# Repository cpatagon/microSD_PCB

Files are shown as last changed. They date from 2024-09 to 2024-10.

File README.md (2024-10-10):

# Diseño de Circuito Impreso para Conexión con microSD

## Trabajo Práctico Final - Diseño de Circuitos Impresos (DCI)

Este repositorio contiene el trabajo práctico final para la asignatura de Diseño de Circuitos Impresos, parte de la carrera de posgrado en FIUBA.

**Autor:** Luis Gómez  
**Título del Trabajo:** Diseño de Circuito Impreso para Conexión con microSD  
**Descripción:** El proyecto consiste en diseñar una PCB para un conector microSD utilizando KiCad. El objetivo es desarrollar un esquema que incorpore el conector microSD con la correcta asignación de pines para alimentación y comunicación. Posteriormente, se optimizará el diseño de la PCB para asegurar un trazado eficiente de las señales. Finalmente, se generarán los archivos Gerber necesarios para la fabricación de la PCB, fomentando habilidades en el diseño y preparación de circuitos impresos para la producción.

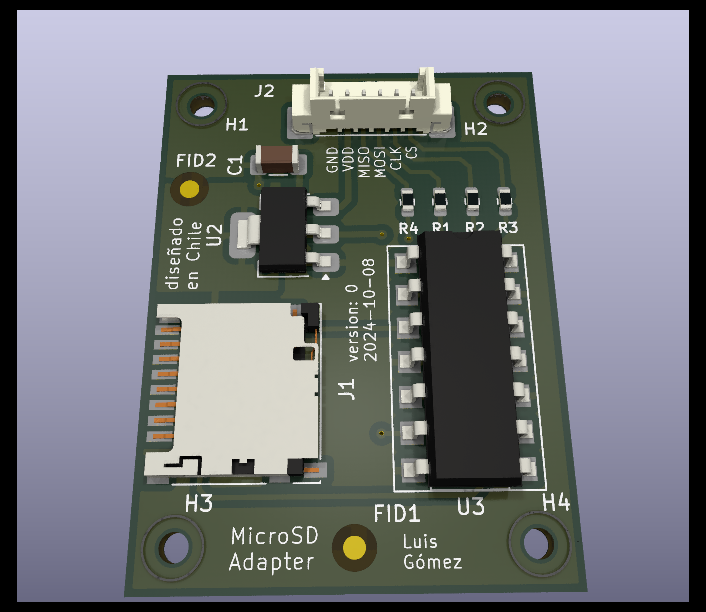
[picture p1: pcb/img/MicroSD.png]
figura 3D de la PCB desarrollada


## Licencia

Este trabajo se encuentra bajo la licencia de hardware abierto. GNU GENERAL PUBLIC LICENSE Version 3, 29 June 2007

## Estructura del Trabajo Práctico Final

* **doc**: Información propia sobre el circuito, incluyendo:
  * [documentación del proyecto](./doc/README.md)
  * [documentación propuesta](./doc/propuesta/README.md)

* **info**: Información recopilada de fuentes externas, como:
  * [información de fuentes externas](./info/README.md)

* **pcb**: Archivos de diseño esquemático y de la PCB.
  * [readme diseño PCB](./pcb/README.md)
  * [PCB Checklist](./pcb/Checklist/README.md)

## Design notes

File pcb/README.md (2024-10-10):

# Proyecto MicroSD: Adaptador PCB

## 1. Información del Proyecto
- **Nombre del diseñador:** Luis Gómez
- **Email:** lgomez@patagones.cl
- **Nombre del proyecto:** PCB microSD
- **Repositorio:** [https://github.com/cese-dci/tpf24a-cpatagon](https://github.com/cese-dci/tpf24a-cpatagon)
- **Revisión realizada por:** Luis Gómez
- **Fecha de la revisión:** 9/10/2024
- **Fecha último commit:** Wed Oct 9 19:16:56 2024 -0300
- **Curso CESE - PCB:** DCI24A

## 2. Resumen Ejecutivo
Este proyecto consiste en el diseño de un adaptador PCB para tarjetas MicroSD, destinado a facilitar la integración de almacenamiento externo en sistemas embebidos. El diseño se enfoca en la compatibilidad con interfaces de 3.3V y 5V, utilizando componentes SMD para minimizar el tamaño y mejorar el rendimiento.

## 3. Especificaciones Técnicas del PCB

| Característica | Valor |
|---|---|
| Cantidad de capas | 2 |
| Terminación superficial | HASL con Plomo |
| Disposición de componentes | Un lado |
| Tecnología de componentes | SMD |
| Serigrafía | 1 cara |
| Grillas utilizadas | 0,5 mm, 0,25 mm, 0,1 mm |
| Anchos de pistas | 0,35 mm y 0,5 mm |
| Vías/agujeros | 0,7 mm / 0,3 mm |
| Clearance (DRC default) | Sin errores |
| Fabricante | [PCB Chile](https://pcb-chile.cl/) |

## 4. Componentes Principales

### 4.1 Integrado 74LVC125A
- **Función:** Buffer cuádruple de tres estados con entradas tolerantes a 5V.
- **Aplicación:** Adaptación de niveles lógicos y aislamiento de señales.
- **Diagrama:**

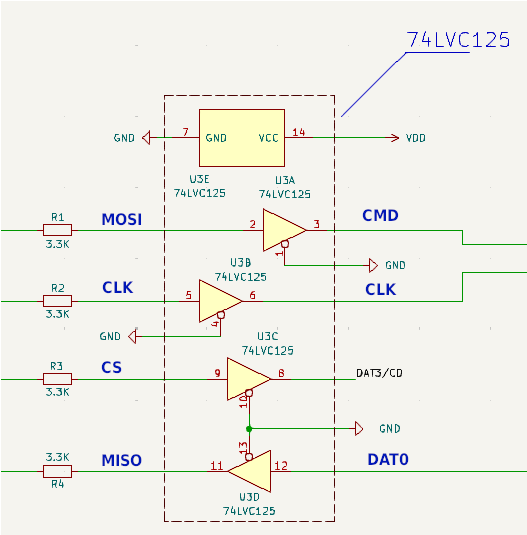
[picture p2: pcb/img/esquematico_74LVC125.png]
Diagrama lógico 74LVC125A
    
  *Figura 1: Diagrama lógico 74LVC125A*

- **Huella:**

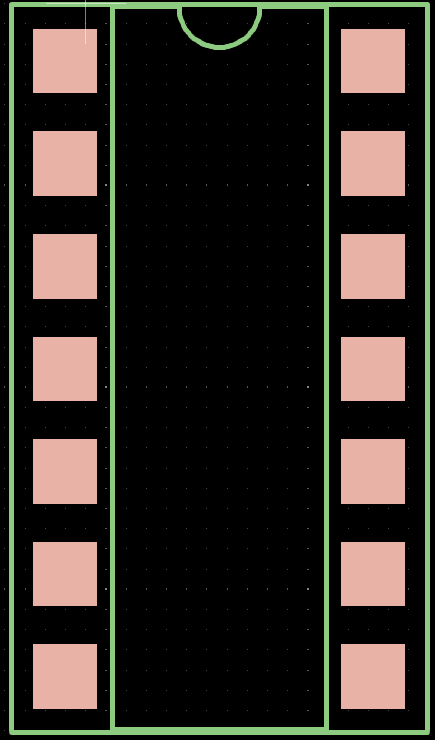
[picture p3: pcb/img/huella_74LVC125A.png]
Huella 74LVC125A
    
  *Figura 2: Huella del integrado 74LVC125A*

### 4.2 Regulador AMS1117
- **Función:** Regulador de voltaje lineal de baja caída.
- **Especificaciones:** Hasta 1A de corriente de salida, comúnmente usado para regular 5V a 3.3V.
- **Diagrama:**

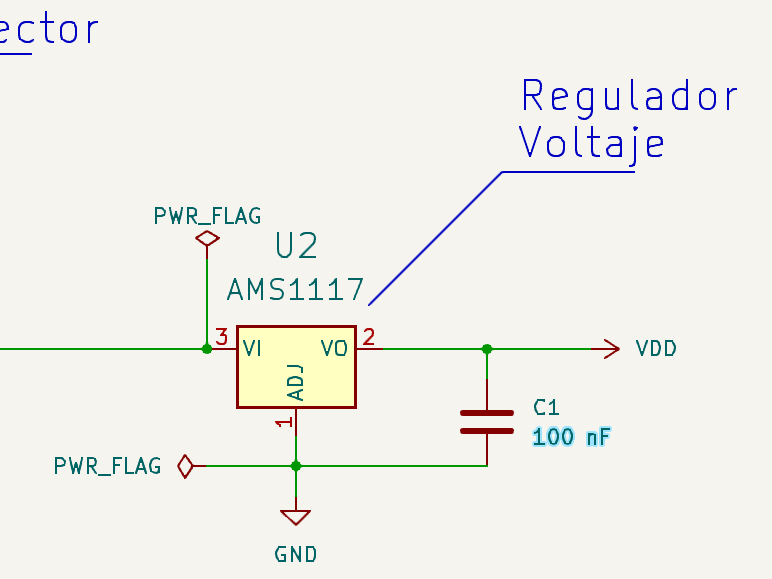
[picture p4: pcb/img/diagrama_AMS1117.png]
Diagrama AMS1117
    
  *Figura 3: Diagrama lógico del regulador AMS1117*

- **Huella:**

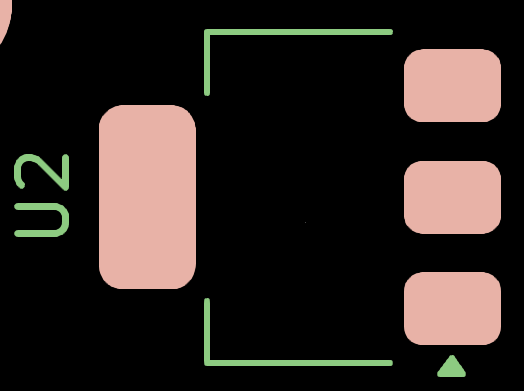
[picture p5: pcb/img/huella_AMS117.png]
Huella AMS1117
    
  *Figura 4: Huella del regulador AMS1117*

### 4.3 Conector MicroSD
- **Función:** Interfaz física para la tarjeta MicroSD.
- **Diagrama:**

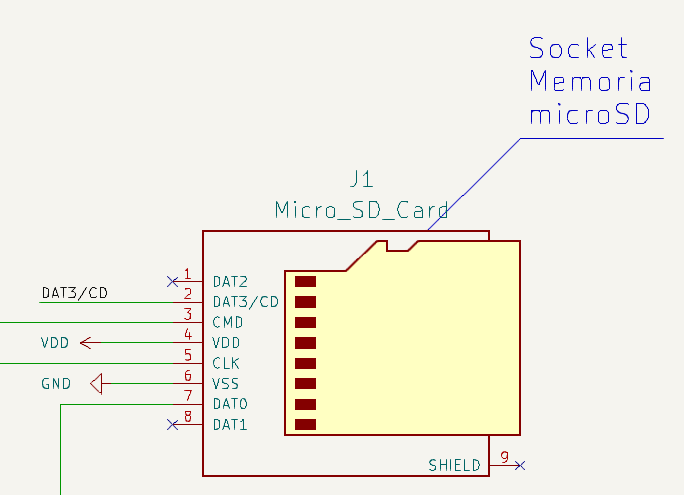
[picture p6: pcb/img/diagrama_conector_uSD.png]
Diagrama conector MicroSD
    
  *Figura 5: Diagrama del conector MicroSD*

- **Huella:**

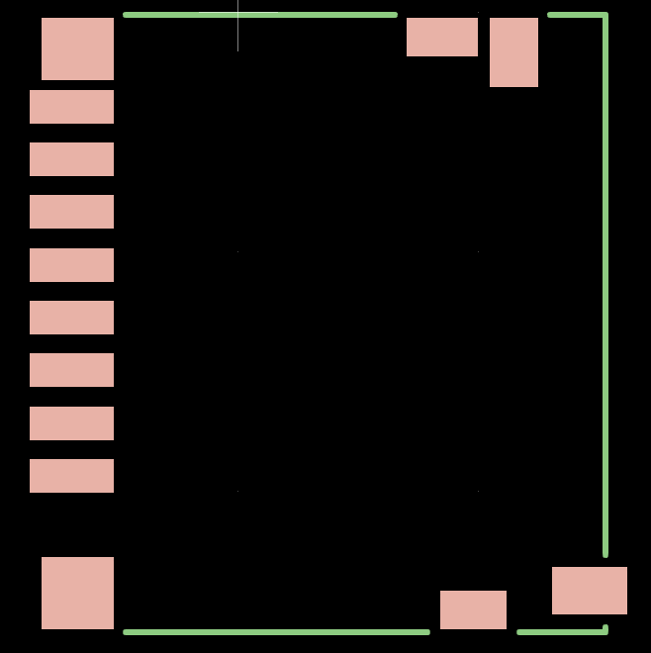
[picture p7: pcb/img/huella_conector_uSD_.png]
Huella conector MicroSD
    
  *Figura 6: Huella del conector MicroSD*

## 5. Diseño del PCB

### 5.1 Esquemático General
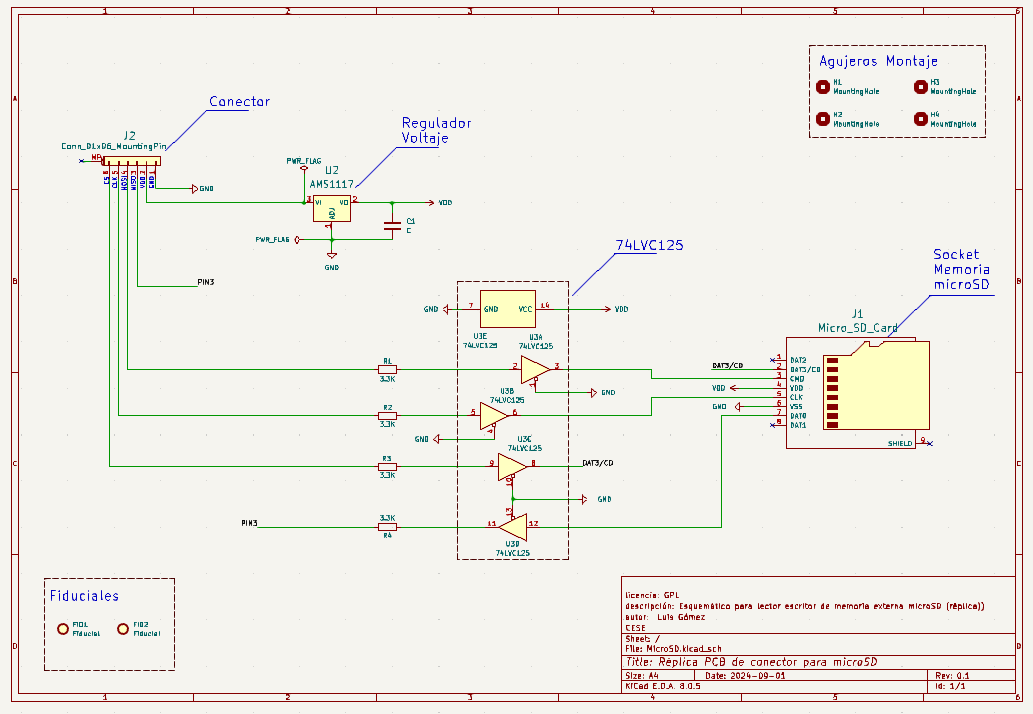
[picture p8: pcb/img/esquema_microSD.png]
Esquemático general
  
*Figura 7: Esquemático general de la PCB MicroSD*

Para más detalles, consulte el [PDF del esquemático completo](PDF/MicroSD.pdf).

### 5.2 Vista General del PCB
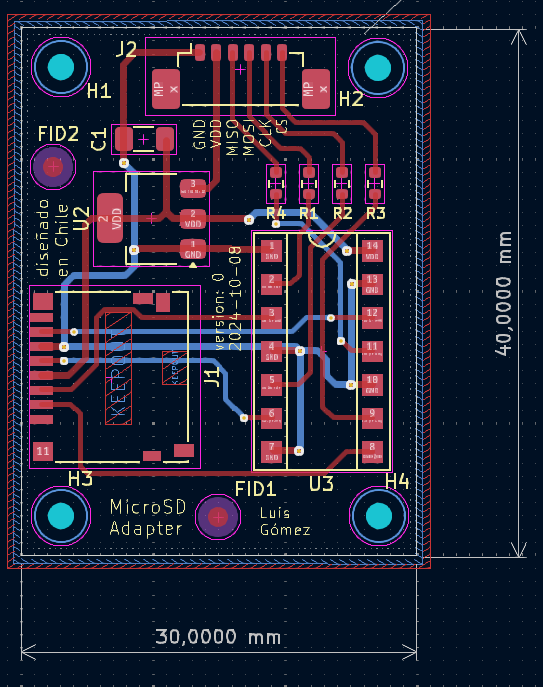
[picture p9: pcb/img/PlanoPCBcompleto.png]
Vista general PCB
  
*Figura 8: Vista general de la PCB para MicroSD*

### 5.3 Huellas de Componentes en PCB
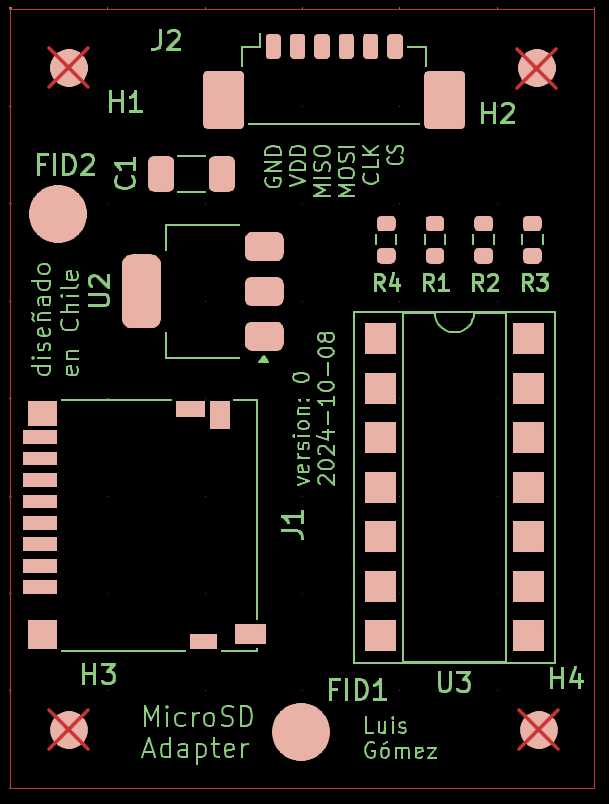
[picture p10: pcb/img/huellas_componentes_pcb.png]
Huellas de componentes
  
*Figura 9: Gerber general con las principales huellas de la PCB*

## 6. Modelos 3D

### 6.1 Vista General 3D
Modelo 3D general  
*Figura 10: Vista general del modelo 3D de la PCB MicroSD*

### 6.2 Vista Frontal 3D
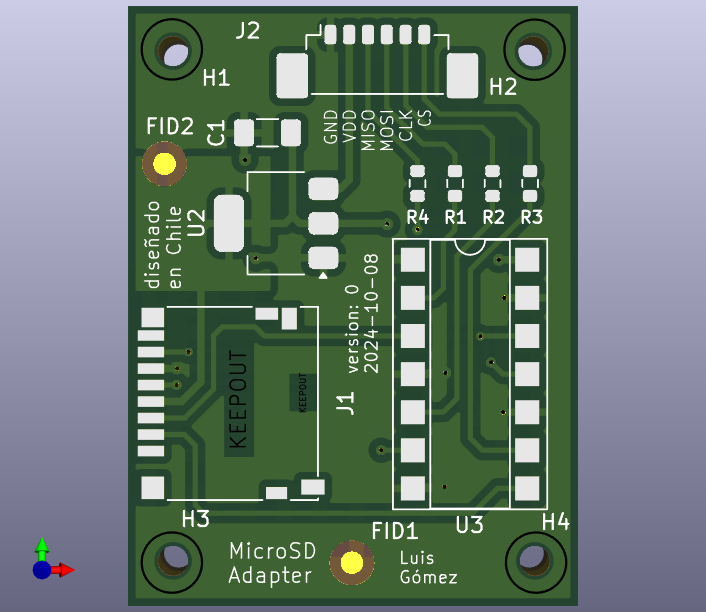
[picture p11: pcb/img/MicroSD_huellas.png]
Vista frontal 3D
  
*Figura 11: Vista frontal del modelo 3D con huellas de componentes*

### 6.3 Vista Trasera 3D
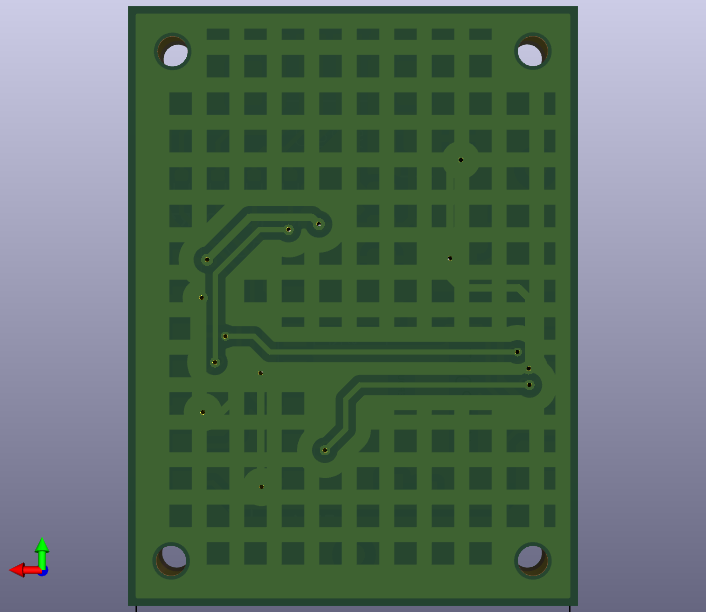
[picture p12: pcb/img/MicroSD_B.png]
Vista trasera 3D
  
*Figura 12: Vista trasera del modelo 3D*

## 7. Archivos del Proyecto

### 7.1 Archivos Gerber
Los archivos Gerber necesarios para la fabricación se encuentran en la [carpeta Gerber](Gerber).

### 7.2 Archivos de PCB
Los archivos de diseño de PCB se encuentran en la [carpeta PCB](MicroSD).

- [Archivo PCB Kicad](MicroSD/MicroSD.kicad_pcb)
- [Archivo Esquematico (sch) Kicad](MicroSD/MicroSD.kicad_sch)

#### Estructura del directorio

```
└── MicroSD
    ├── MicroSD.kicad_pcb (PCB)
    ├── MicroSD.kicad_prl
    ├── MicroSD.kicad_pro
    ├── MicroSD.kicad_sch (Esquematico)
    └── sym-lib-table
```

### 7.3 Bibliotecas de Símbolos y Huellas
Las bibliotecas personalizadas utilizadas en este proyecto se encuentran en la [carpeta Libreria](Libreria).

## 8. Consideraciones de Diseño
- Se utilizó un enfoque de ruteo de dos capas para optimizar el espacio y reducir la interferencia electromagnética.
- Se implementaron planos de tierra en ambas capas para mejorar el manejo de EMI.
- Se calculo el ancho mínimo de cada pista de acuerdo a la norma IPC 2221. Se calculo fue hecho con una corriente máxima de 1A, aumento de la temperatura de 10°C y longitud máxima de pista de 100 mm. El ancho de pista resultante fue de 0,3 mm y un grosor de 1 oz de Cu. 

## 9. Próximos Pasos
- Fabricación de prototipos para pruebas y validación.
- Realización de pruebas de funcionamiento a diferentes voltajes (3.3V y 5V).
- Análisis térmico bajo carga máxima.
- Consideración de mejoras para futuras versiones, como la integración de un controlador USB o soporte para velocidades UHS-I.
- Las pistas de datos se diseñaran con impedancia controlada para mantener la integridad de la señal en altas velocidades.

## 10. Conclusiones
Este diseño de PCB para adaptador MicroSD ofrece una solución compacta y versátil para la integración de almacenamiento externo en sistemas embebidos, con consideraciones especiales para la compatibilidad de voltajes y el rendimiento de alta velocidad.

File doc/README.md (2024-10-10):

# Documentación Detallada: PCB Adaptador MicroSD

## 1. Información del Proyecto
- **Nombre del diseñador:** Luis Gómez
- **Email:** lgomez@patagones.cl
- **Nombre del proyecto:** Adaptador PCB MicroSD de Bajo Costo
- **Repositorio:** [https://github.com/cese-dci/tpf24a-cpatagon](https://github.com/cese-dci/tpf24a-cpatagon)
- **Versión:** 1.0
- **Fecha de última actualización:** 9 de octubre de 2024

## 2. Resumen Ejecutivo
Este proyecto consiste en el diseño de un adaptador PCB para tarjetas MicroSD, enfocado en proporcionar una solución de bajo costo y alta confiabilidad para aplicaciones embebidas. El diseño incorpora adaptación de niveles lógicos para compatibilidad con sistemas de 3.3V y 5V, utilizando componentes SMD para minimizar el tamaño y mejorar el rendimiento.

## 3. Notas de Ingeniería

### 3.1 Arquitectura del Diseño
- **Capas PCB:** Diseño de dos capas para equilibrar complejidad y costo.
- **Tecnología de componentes:** SMD exclusivamente, para reducción de tamaño y mejora de rendimiento en altas frecuencias.
- **Dimensiones del PCB:** 30mm x 20mm (optimizado para portabilidad).

### 3.2 Componentes Clave
1. **Buffer 74LVC125A:**
   - Función: Adaptación de niveles lógicos entre 5V y 3.3V.
   - Justificación: Permite la interoperabilidad con sistemas de diferentes voltajes.

2. **Regulador AMS1117:**
   - Función: Proporciona regulación estable de 3.3V para la tarjeta MicroSD.
   - Características: Baja caída de tensión, capacidad de corriente de 1A.

3. **Conector MicroSD:**
   - Tipo: Push-pull para fácil inserción y extracción.
   - Blindaje: Metálico para reducir EMI.

### 3.3 Consideraciones de Diseño
- **Integridad de la Señal:** Trazado de pistas críticas con impedancia controlada (90 ohms diferencial para líneas de datos SD).
- **EMI/EMC:** Implementación de planos de tierra en ambas capas para reducir interferencias. 
- **Térmica:** Área de cobre ampliada alrededor del regulador AMS1117 para mejorar la disipación térmica.

## 4. Notas de Aplicación

### 4.1 Casos de Uso Previstos
- Sistemas de registro de datos portátiles.
- Actualización de firmware en dispositivos embebidos.
- Almacenamiento expandible para proyectos de IoT.

### 4.2 Guía de Integración
1. **Conexión eléctrica:**
   - Pines de entrada: VCC (5V), GND, MOSI, MISO, SCK, CS.
   - Salida: Interfaz estándar MicroSD.

2. **Configuración de software:**
   - Compatible con bibliotecas estándar de SPI para MicroSD.
   - Ejemplo de código para Arduino y STM32 disponible en el repositorio.

### 4.3 Limitaciones y Precauciones
- Velocidad máxima de operación: 25 MHz (limitado por el buffer 74LVC125A).
- No compatible con el modo UHS-II de tarjetas SD de alta velocidad.

## 5. Estudios Previos y Estado del Arte

### 5.1 Análisis de Mercado
- Revisión de 10 adaptadores MicroSD comerciales (Adafruit, SparkFun, genéricos).
- Tendencia observada: Miniaturización y aumento de la velocidad de transferencia.

### 5.2 Avances Tecnológicos Relevantes
- Nuevos buffers de nivel lógico con menor consumo y mayor velocidad.
- Conectores MicroSD con mejor retención y durabilidad.

### 5.3 Estándares y Normativas
- Cumplimiento con especificaciones SD Association versión 7.0.
- Diseño ajustado a directrices de IPC-2221 para PCB.

## 6. Cálculos y Análisis

### 6.1 Análisis de Potencia
- Consumo estimado:
  - Buffer 74LVC125A: 8 mA (típico)
  - MicroSD (activa): 100 mA (máximo)
  - Regulador AMS1117 (pérdidas): 170 mW (típico con Vin=5V, Iout=100mA)
- Potencia total estimada: < 0.7 W

### 6.2 Análisis Térmico
- Temperatura máxima del regulador AMS1117:
  - Tj = Ta + (Pd * θja) = 25°C + (0.17W * 65°C/W) ≈ 36°C
  - Margen seguro, no requiere disipador adicional.

### 6.3 Cálculos de Ancho de Pista
- Pistas de señal (0.35 mm):
  - Capacidad de corriente: 0.5A a 10°C de elevación de temperatura.
- Pistas de alimentación (0.5 mm):
  - Capacidad de corriente: 1A a 10°C de elevación de temperatura.

### 6.4 Análisis de Integridad de Señal
- Simulación SPICE de líneas diferenciales SD:
  - Rise time: < 1 ns
  - Overshoot: < 10%

## 7. Diagramas y Visualizaciones

### 7.1 Esquemático General
Esquema General
*Figura 1: Esquemático completo del adaptador MicroSD*

### 7.2 Diagrama de Bloques Funcionales
Diagrama de Bloques
*Figura 2: Diagrama de bloques funcionales del adaptador*

### 7.3 Diseño PCB
Huella PCB
*Figura 3: Layout de PCB mostrando huellas de componentes*

### 7.4 Renderizado 3D
Modelo 3D
*Figura 4: Renderizado 3D del PCB ensamblado*

## 8. Presupuesto y Análisis de Costos

### 8.1 Costos de Fabricación (para 100 unidades)
- PCB (PCB Chile): $1.72 USD/unidad (https://pcb-chile.cl/quote)

### 8.2 Costos de Componentes (precios unitarios)
- 74LVC125A: $0.1 USD (https://www.mouser.cl/c/?q=74LVC125A )
- AMS1117: $0.0264 USD  (https://es.aliexpress.com/ )
- Conector MicroSD: $1.47 USD (https://www.mouser.cl/)
- Otros componentes pasivos: $0.50 USD

### 8.3 Costo Total Estimado
- Costo por unidad (incluyendo fabricación y componentes): $7.50 USD
- Precio de venta sugerido: $14.99 USD
- Margen bruto estimado: 50%

## 9. Conclusiones y Trabajo Futuro

### 9.1 Logros del Diseño Actual
- Adaptador MicroSD de bajo costo con adaptación de nivel lógico integrada.
- Tamaño compacto y diseño optimizado.

### 9.2 Áreas de Mejora
- Explorar la posibilidad de integrar RTC
- Investigar opciones para soportar velocidades UHS-I en futuras revisiones.

### 9.3 Próximos Pasos
- Fabricación de prototipo y pruebas de campo.

---

Este documento está sujeto a revisiones y actualizaciones. Última revisión: 09/10/2024.

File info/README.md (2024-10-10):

# Información Complementaria PCB MicroSD

## Hojas de Datos

### 1. Buffer 74LVC125A
- **Fabricante:** Texas Instruments
- **Enlace:** [Hoja de datos 74LVC125A](https://www.ti.com/lit/ds/symlink/sn74lvc125a.pdf)
- **Importancia:** Crucial para la adaptación de niveles lógicos entre 3.3V y 5V.

### 2. Regulador AMS1117
- **Fabricante:** Advanced Monolithic Systems
- **Enlace:** [Hoja de datos AMS1117](http://www.advanced-monolithic.com/pdf/ds1117.pdf)
- **Importancia:** Proporciona la regulación de voltaje necesaria para la tarjeta MicroSD.

### 3. Conector MicroSD
- **Fabricante:** Molex
- **Enlace:** [Hoja de datos Conector MicroSD](https://www.molex.com/pdm_docs/sd/5033981892_sd.pdf)
- **Importancia:** Especificaciones mecánicas y eléctricas para el diseño del footprint.

## Notas de Aplicación

### 1. Diseño de PCB para Tarjetas SD
- **Título:** "PCB Design Guidelines for SD Memory Cards"
- **Fuente:** SD Association
- **Enlace:** [Guía de Diseño SD](https://www.sdcard.org/downloads/pls/pdf/index.php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)
- **Relevancia:** Proporciona pautas específicas para el diseño de PCB compatible con tarjetas SD.

### 2. Consideraciones de EMI en Diseño de PCB
- **Título:** "EMI Reduction Techniques in PCB Design"
- **Fuente:** Analog Devices
- **Enlace:** [Técnicas de Reducción de EMI](https://www.analog.com/media/en/training-seminars/tutorials/MT-095.pdf)
- **Relevancia:** Ayuda a minimizar la interferencia electromagnética en el diseño.

## Información de Productos Comerciales

### 1. Adaptador MicroSD de Adafruit
- **Producto:** Adafruit MicroSD Card Breakout Board
- **Enlace:**:
  - [Adafruit MicroSD Breakout](https://www.adafruit.com/product/254)
  - [Github](https://github.com/adafruit/MicroSD-breakout-board)
- **Uso:** Referencia para comparar características y diseño.

### 2. Módulo MicroSD de SparkFun
- **Producto:** SparkFun MicroSD Transflash Breakout
- **Enlace:** [SparkFun MicroSD Breakout](https://www.sparkfun.com/products/544)
- **Uso:** Inspiración para el diseño y comparación de funcionalidades.

## Recursos de Internet

### 1. Tutorial de Diseño de PCB
- **Título:** "KiCad PCB Design Tutorial"
- **Fuente:** Contextual Electronics
- **Enlace:** [Tutorial KiCad](https://contextualelectronics.com/courses/getting-to-blinky-4-0/)
- **Aplicación:** Guía paso a paso para el diseño de PCB en KiCad.

### 2. Foro de Diseño de PCB
- **Nombre:** EEVblog Electronics Community Forum
- **Enlace:** [Foro EEVblog](https://www.eevblog.com/forum/eda/)
- **Uso:** Discusiones y consejos de la comunidad sobre diseño de PCB.

### 3. Calculadora de Ancho de Pista PCB
- **Herramienta:** PCB Trace Width Calculator
- **Enlace:** [Calculadora de Ancho de Pista](https://www.4pcb.com/trace-width-calculator.html)
- **Aplicación:** Utilizada para determinar el ancho óptimo de las pistas en el PCB.

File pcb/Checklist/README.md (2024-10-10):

# PCB Design Checklist

## Documentación y Organización
| PASA | Ítem | Comentarios | Se pide en la asignatura? |
|---|---|---|---|
| SI | Puso en el directorio /doc/propuesta las imágenes y pdfs del circuito original? Use la información que proporcionó en el formulario. | | SI |
| SI | En el directorio /info colocó las hojas de datos de los chips más importantes del circuito? En particular es de interés la hoja de datos donde figuren los footprints. Como es un ejercicio, no coloque manuales extensos o archivos muy grandes. | | SI |
| SI | Organizó adecuadamente en directorios? Por ejemplo en el directorio del diseño KiCad solo puso los archivos KiCad o mezcló ahí hojas de datos y otros archivos? | | SI |

## Esquemático
| PASA | Ítem | Comentarios | Se pide en la asignatura? |
|---|---|---|---|
| SI | El rótulo tiene el título del diseño? | | SI |
| SI | El título da una idea de que trata el circuito? | | SI |
| SI | Si se trata de la modalidad "Réplica" dice réplica en el título? | | SI |
| SI | El rótulo tiene nombre del autor ? | | SI |
| SI | El rótulo tiene información de la licencia? La licencia es de uso libre como OHL, BSD, GPL o CC BY 4.0 | | SI |
| SI | Las referencias son consecutivas y sin saltos? Por ejemplo R1, R2, R5, R6 (le falta R3). | | SI |
| SI | Están todos los campos de valor de los componentes completados correctamente? | | SI |
| SI | Los campos referencia y valor, se ven claramente y no se superponen con otras cosas? | | SI |
| SI | Los componentes importantes como semiconductores y conectores fuera de lo común, tienen código de catálogo? | | SI |
| ? | Tiene bloques funcionales delimitados claramente? | Los separé espacialmente | SI |
| SI | Hay un texto con el nombre o descripción de cada bloque? | | SI |
| NO | Tiene las notas aclaratorias necesarias? | | SI |
| NO | El ERC da cero errores? Si da errores, no hay forma de sacarlos? | | SI |
| SI | Colocó símbolos para los agujeros y los fiduciales? | | SI |
| SI | Las conexiones más importantes del circuito están dibujadas o hizo "abuso" de etiquetas? | | SI |
| SI | Usó adecuadamente las referencias de tensión para evitar líneas innecesarias? | | SI |
| SI | Uso adecuadamente las referencias de alimentación, o colocó unas pocas y desde ahí salen conexiones a todo el esquemático? | | SI |
| SI | Usó etiquetas locales para conectar dentro de la hoja o usó globales innecesariamente? | | SI |
| SI | Hay algunas señales o nodos que merezcan ser identificadas con una etiqueta (por ejemplo líneas de clock o reset, o líneas principales de comunicación entre bloques). | | SI |
| NO | Si es de múltiples hojas, separó en forma inteligente? Hay más de dos niveles? En caso de ser simple hoja, entra adecuadamente o se nota la falta de espacio en la hoja? | | SI |
| SI | Tiene uniones (junctions) en lugares donde no son necesarias? Hizo un esfuerzo por evitar superponer puntos de conexión con uniones? | | SI |
| SI | Intentó seguir un flujo de izquierda a derecha siempre que se puede? | | SI |
| SI | Intentó dibujar las ramas de arriba hacia abajo según tensiones de alimentación positivas y negativas? | | SI |
| SI | Si es un esquemático jerárquico, las alimentaciones no deben pasarse por etiquetas jerárquicas. | | SI |
| SI | Los circuitos integrados, tiene su disposición de pines ordenados para facilitar el diagrama o están según el pinout físico? | | SI |
| NO | Hay algún circuito integrado o componente que si se dibuja como multiparte tendría un gran impacto positivo en la prolijidad o organización? | | SI |

## Asociación de Huellas
| PASA | Ítem | Comentarios | Se pide en la asignatura? |
|---|---|---|---|
| SI | Todos los símbolos tienen una huella asociada | | SI |
| SI | Tiene por lo menos un agujero de sujeción? Se recomienda uno para los PCBs más pequeños y 2 a 4 para los mayores. | | SI |
| SI | Tiene los fiduciales en caso de ser necesarios? | | SI |
| SI | Verificó las dimensiones de los pads con las hojas de datos? | | SI |
| SI | Verificó el paso y todas las distancias de los componentes con su hoja de datos? | | NO |
| NO | Verificó que las numeraciones sean las correctas en relación al esquemático y a la hoja de datos? | | NO |
| NO | Consideró el requisito de componentes 0805 o más grande? Como regla general, pensó en el posible retrabajo de los componentes o en el armado manual de los primeros prototipos? | | SI |

## PCB: Huellas y Posicionamiento
| PASA | Ítem | Comentarios | Se pide en la asignatura? |
|---|---|---|---|
| SI | Trabajó principalmente en mm? | | SI |
| SI | Anotó las grillas que usa? Cuáles son? | | SI |
| SI | Colocó fiduciales en las esquinas en caso de ser necesarios? | | SI |
| SI | Colocó los agujeros al principio y de manera estratégica? | | SI |
| SI | Los conectores están al borde? | | SI |
| SI | Si se trata de una réplica, miró la disposición original para tener ya una disposición tentativa? (se puede adaptar o mejorar, no tiene que ser una réplica exacta, pero analizar el original lo ayudará a pensar un buen posicionamiento. | | SI |

## Modelos 3D y Portabilidad
| PASA | Ítem | Comentarios | Se pide en la asignatura? |
|---|---|---|---|
| SI | Todos los componentes tienen modelo 3D asociado? Si alguno no tiene, intentó buscarlo? | | SI |
| SI | Colocó todos los modelos 3D dentro del repositorio? La operación se realiza fácilmente con la operación de exportar, una vez que todos los modelos 3D están asociados. | | SI |
| SI | Si tiene la posibilidad, baje el repositorio en otro sistema e intente abrir esquemático, PCB y ver la vista 3D. Esto sirve para detectar archivos faltantes en el repo, o rutas absolutas en el diseño. Idealmente se deben usar siempre rutas relativas que apunten a carpetas y archivos dentro del repo. Le puede pedir a un compañero que lo haga si no posee otra computadora o sistema alternativo. | | SI |

## PCB - Documentación
| PASA | Ítem | Comentarios | Se pide en la asignatura? |
|---|---|---|---|
| SI | El rótulo del PCB tiene información similar al esquemático? | | SI |
| SI | Tiene notas adicionales con la terminación superficial elegida? | | SI |
| SI | Tiene notas adicionales con las grillas utilizadas, o las principales que utilizó? | | SI |
| SI | Si es un multicapa, colocó notas con la información del stackup? | | SI |
| SI | Colocó en las notas, qué fabricante consideró? | Esto se pide para que el docente conozca qué fabricante usó como referencia al momento de analizar los límites del diseño. | SI |
| SI | Dibujó las cotas de las dimensiones principales del PCB? (alto y ancho) | | SI |

## PCB - Borde
| PASA | Ítem | Comentarios | Se pide en la asignatura? |
|---|---|---|---|
| SI | El borde de PCB, lo dibujó usando la capa adecuada para tal fin? | | SI |
| SI | El borde de PCB coincide con la grilla más grande que dice haber utilizado? Por ejemplo 1mm o 0,5 mm. | | SI |
| SI | El tamaño de PCB tiene dimensiones coherentes? | Por ejemplo números redondos (salvo requisito especial). Por ejemplo espacios grandes sin aprovechar. | SI |
| SI | Dibujó el margen de seguridad al borde del PCB? Se sugiere por lo menos 0,5 mm. | | SI |
| SI | Dibujó un margen de seguridad para que los componentes y las estructuras de cobre no estén demasiado cerca del borde? | | SI |

## PCB - Distribución
| PASA | Ítem | Comentarios | Se pide en la asignatura? |
|---|---|---|---|
| SI | La distribución de los componentes en el PCB es pareja? | | SI |
| SI | Los componentes están alineados prolijamente entre sí, siempre que se puede? | | |

## PCB - Rellenos de Cobre
| PASA | Ítem | Comentarios | Se pide en la asignatura? |
|---|---|---|---|
| SI | Analizó el balance de cobre? | | SI |
| SI | Utilizó rellenos de cobre, en especial para las tierras involucradas? | | SI |
| SI | Aplicó alivios térmicos? | | SI |
| SI | Los límites de las zonas de rellenos se superponen entre sí y con el borde o aplicó las sugerencias vistas en clase (siempre que la situación lo permita)? | | SI |

## PCB - Pistas
| PASA | Ítem | Comentarios | Se pide en la asignatura? |
|---|---|---|---|
| SI | Configuró los anchos de pistas que usará en el diseño? | | |
| SI | Las pistas que ingresan a los pads, tienen el ancho necesario para no deformarlos? | | SI |
| SI | Utilizó un ancho de pista acorde al tamaño de los pads, a las corrientes involucradas y que superen los límites de fabricación? | | SI |
| SI | Utilizó pistas a 45 siempre que pudo, en vez de pistas a 90 o a cualquier ángulo? | | SI |
| SI | El ruteo está prolijo? Por ejemplo los trazos no tienen quiebres innecesarios, desprolijidades de trazos, segmentos sueltos, pistas descentradas, etc. | | SI |
| SI | Para las pistas que llevan corrientes importantes, realizó el cálculo del ancho necesario? | | |
| SI | Si tiene impedancia controlada, aplicó el ancho necesario, documentó adecuadamente en PCB y en esquemático? | | |

## PCB - Vías
| PASA | Ítem | Comentarios | Se pide en la asignatura? |
|---|---|---|---|
| SI | Configuró las vías que utilizará en el diseño? | | SI |
| SI | Las vías tienen un tamaño adecuado? Analizó los límites de fabricación y las recomendaciones de IPC? | | SI |

## PCB - Clearance y DRC
| PASA | Ítem | Comentarios | Se pide en la asignatura? |
|---|---|---|---|
| SI | Utilizó el mayor clearance posible que le permite el tipo de diseño? Intentó subirlo? | Muchas veces implica colocar márgenes ajustados (menores) para determinados componentes, pero dejando al resto del PCB con márgenes más amplios. | SI |
| SI | Configuró adecuadamente las reglas de diseño? | | SI |
| SI | Dejó al diseño con cero errores de DRC? | | SI |

## PCB - Serigrafía
| PASA | Ítem | Comentarios | Se pide en la asignatura? |
|---|---|---|---|
| SI | Todas las referencias se leen correctamente y están prolijas? | | SI |
| SI | Ocultó las referencias de fiduciales y agujeros? | Normalmente no son necesarias. | SI |
| SI | Para optimizar costos, muchas veces solo se aplica serigrafía de un solo lado, cuando realmente no es necesario aplicarla de ambos lados, o se puede pasar todo a una cara. Analizó este tema? | | SI |
| SI | Agregó el nombre del circuito? | | SI |
| SI | Agregó una fecha o un número de versión? | | SI |
| SI | Agregó su nombre y/o apellido? | | Opcional |
| SI | Agregó la leyenda "Diseñado en PAIS" o "Industria PAIS"? | | Opcional |

## PCB - Verificación
| PASA | Ítem | Comentarios | Se pide en la asignatura? |
|---|---|---|---|
| NO | Tiene pines para testing? | | NO |
| NO | Tiene leds para las tensiones o señales importantes? | | NO |
| NO | Los tamaños de agujeros para los pines tienen la holgura necesaria para que el pin no entre a presión? | | NO |
| NO | Tiene el verificador de capas? | | Solo si es multicapa |
| NO | Tiene cupón de prueba? Hace falta? | | NO |

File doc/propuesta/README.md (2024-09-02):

## Propuesta

En este directorio se incluye la información presentada al momento de acordar la propuesta del Trabajo Práctico con el docente. A continuación se detallan los elementos clave:

### Fotos e Imágenes

Si el trabajo es una réplica, se presentan las imágenes de las placas de ambos lados:

* **Placa MicroSD (Vista Superior):**  
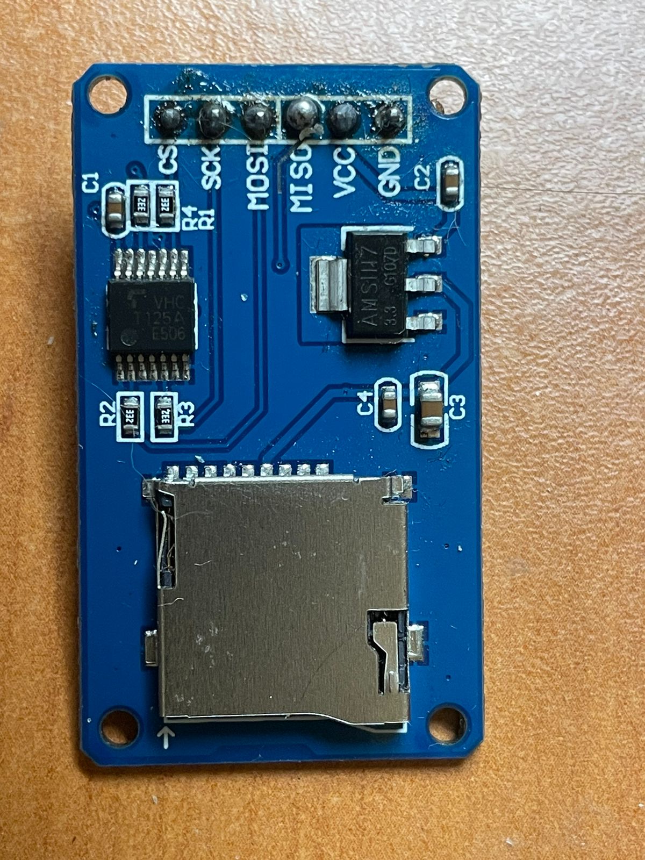
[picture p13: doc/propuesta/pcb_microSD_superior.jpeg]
Vista Superior
  

* **Placa MicroSD (Vista Posterior):**  
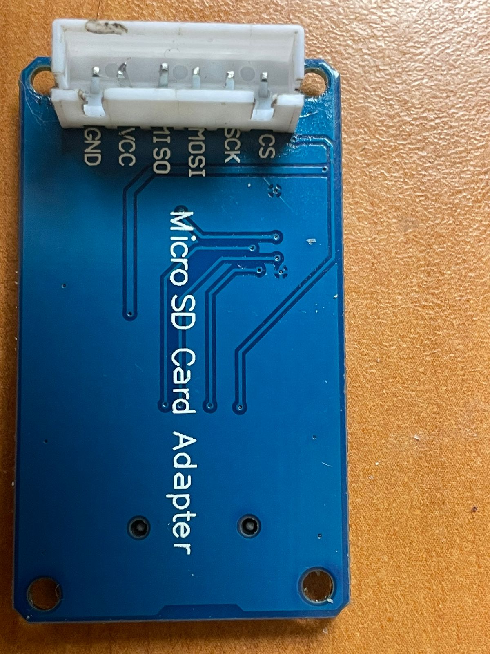
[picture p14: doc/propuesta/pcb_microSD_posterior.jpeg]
Vista Posterior
  

### Circuito Esquemático de Referencia

A continuación, se incluye el esquema de referencia del circuito:

* **Esquemático del Módulo MicroSD:**  
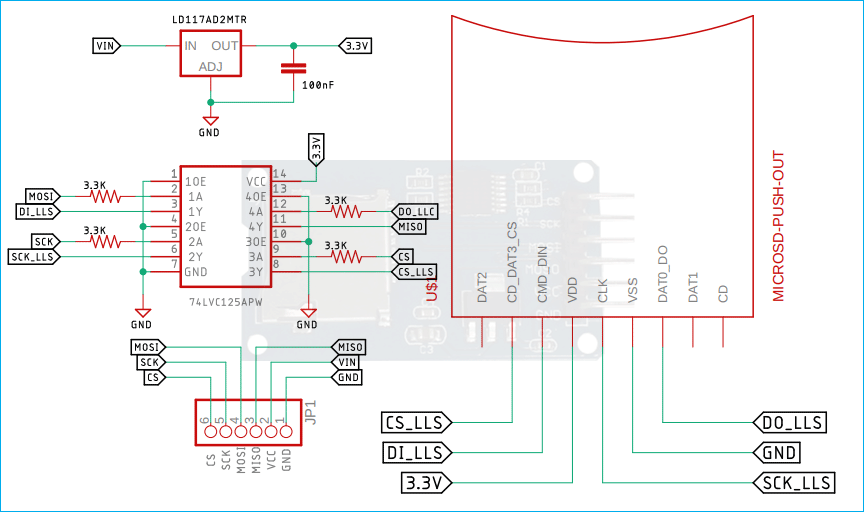
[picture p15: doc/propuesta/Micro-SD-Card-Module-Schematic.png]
Esquemático MicroSD
  

### Documentación Técnica

Se incluyen los siguientes documentos técnicos relacionados con los componentes utilizados en el circuito:

* [AMS1117 - Datasheet](AMS1117.PDF)
* [SN74LVC125A - Datasheet](SN74LVC125A.PDF)

### Información Adicional

Si el trabajo es una tesis, a continuación se resumen las pruebas y prototipos realizados, así como el objetivo del circuito:

* **Resumen del Objetivo del Circuito:**  
  (Incluir aquí un resumen breve del objetivo o función principal del circuito, si es un trabajo de tesis)

* **Pruebas y Prototipos Cableados:**  
  (Incluir imágenes o descripciones de las pruebas realizadas)

### URLs o Información de Origen

Para mayor información y referencias, se incluyen los enlaces y recursos utilizados para definir el TP en el formulario de propuesta:

* **URLs e Información de Origen:**  
  (Incluir aquí las URLs o información relevante que se haya utilizado para la propuesta)

### Notas Adicionales

Cualquier otra nota o comentario que se haya utilizado para definir el TP en el formulario de propuesta se incluirá aquí.

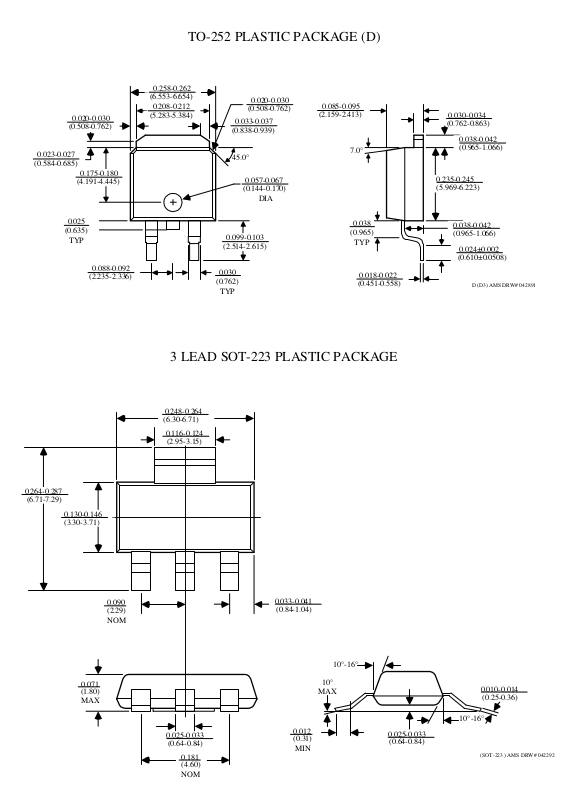
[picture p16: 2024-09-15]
info/img/huella_AMS1117.png

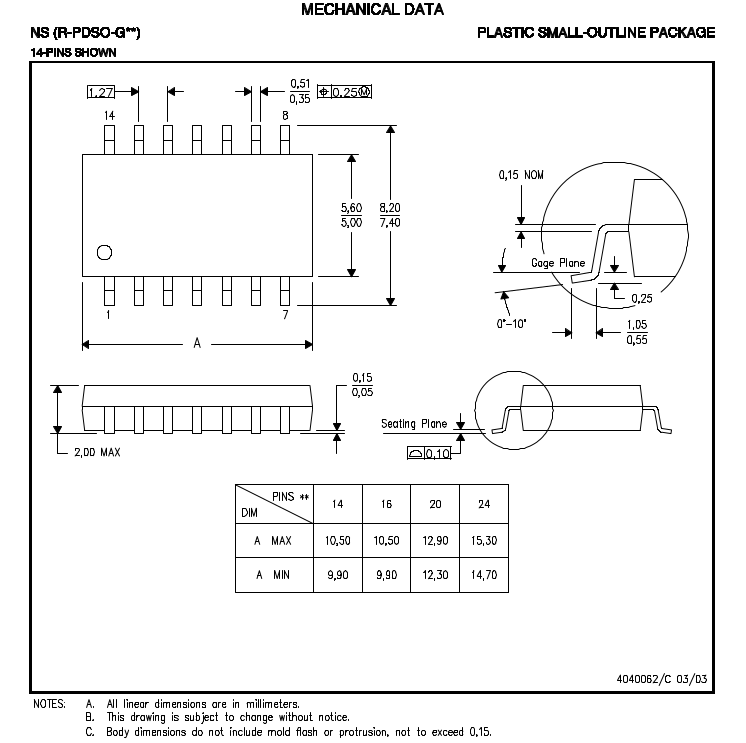
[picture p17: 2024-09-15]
info/img/huella_74LVC125A.png

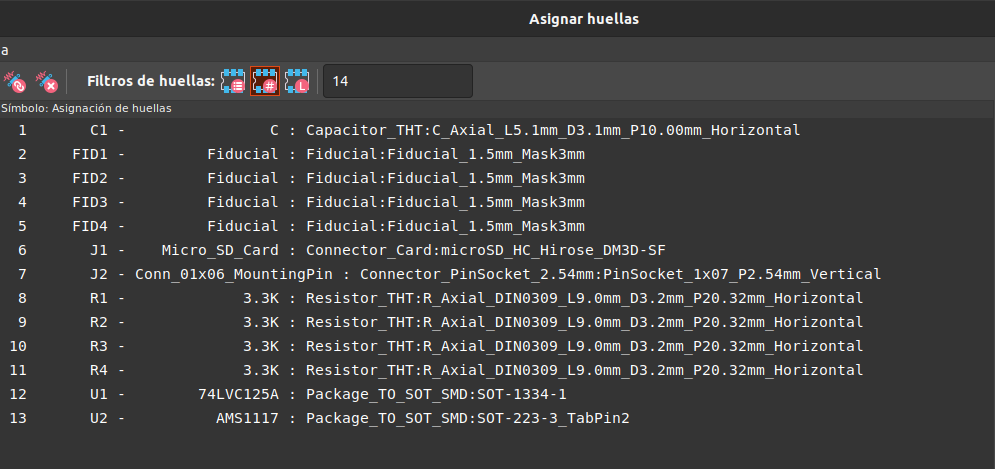
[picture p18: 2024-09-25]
doc/img/huellas.png

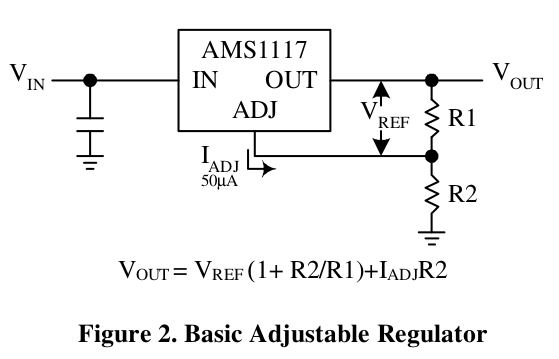
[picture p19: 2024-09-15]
info/img/esquematico_AMS117.png

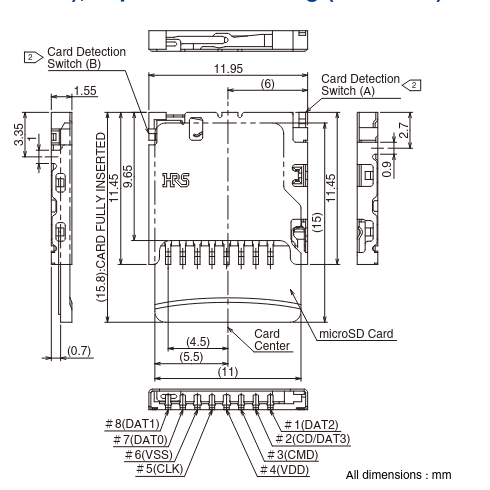
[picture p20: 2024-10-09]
doc/propuesta/Connector_CardmicroSD_HC_Hirose_DM3D-SF.png

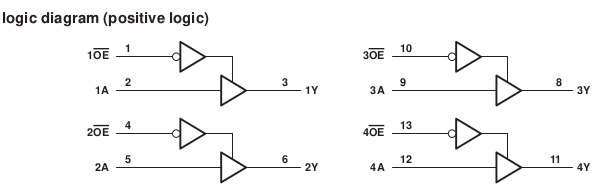
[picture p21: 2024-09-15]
info/img/diagrama_74LVC125A.png

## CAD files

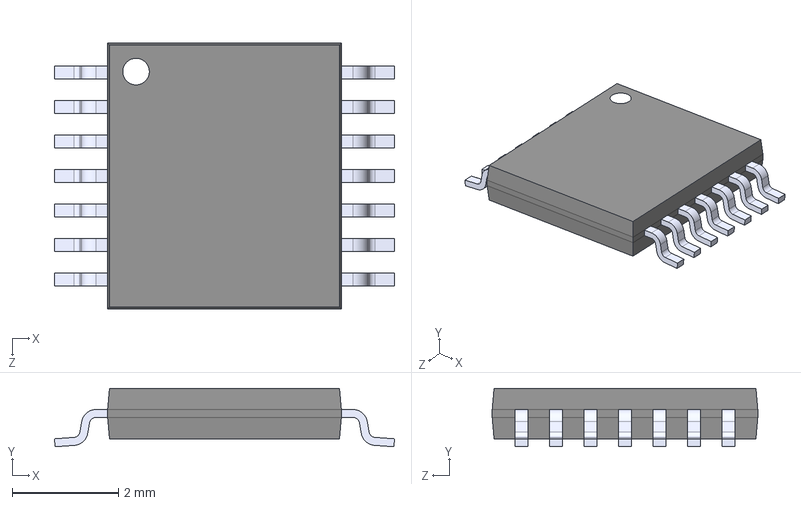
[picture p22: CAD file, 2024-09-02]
pcb/Libreria/74LVC125APW_118.step
6.40 x 1.10 x 5.00 mm

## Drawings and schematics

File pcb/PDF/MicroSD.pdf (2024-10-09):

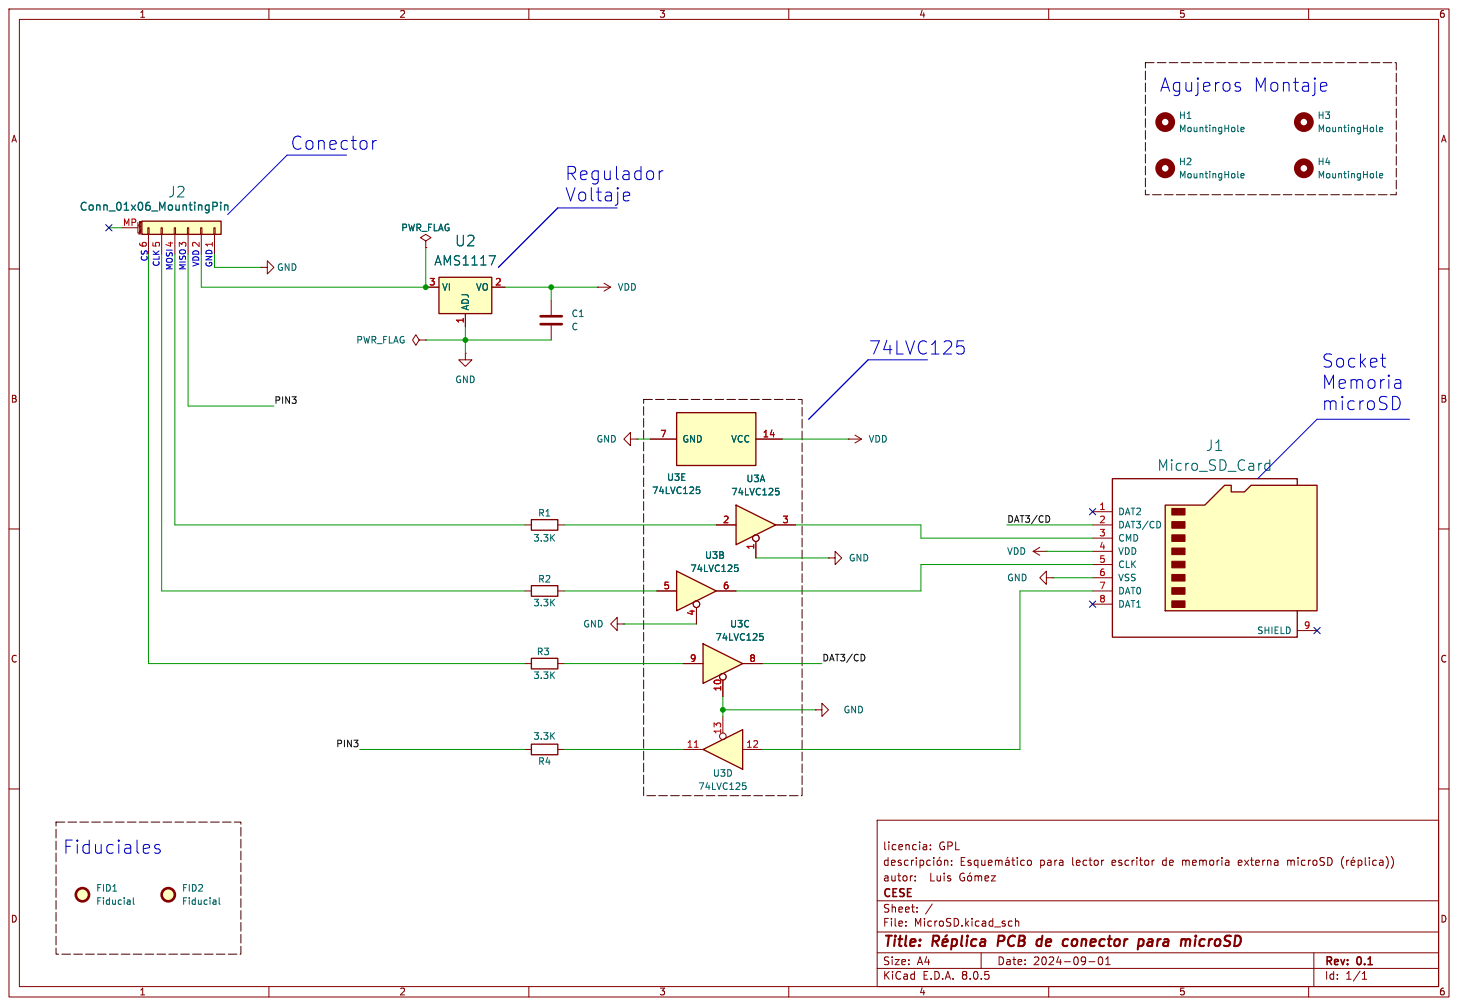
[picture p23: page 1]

File: MicroSD.kicad_sch Sheet: / CESE

Id: 1/1 Title: þÿRéplica PCB de conector para microSD

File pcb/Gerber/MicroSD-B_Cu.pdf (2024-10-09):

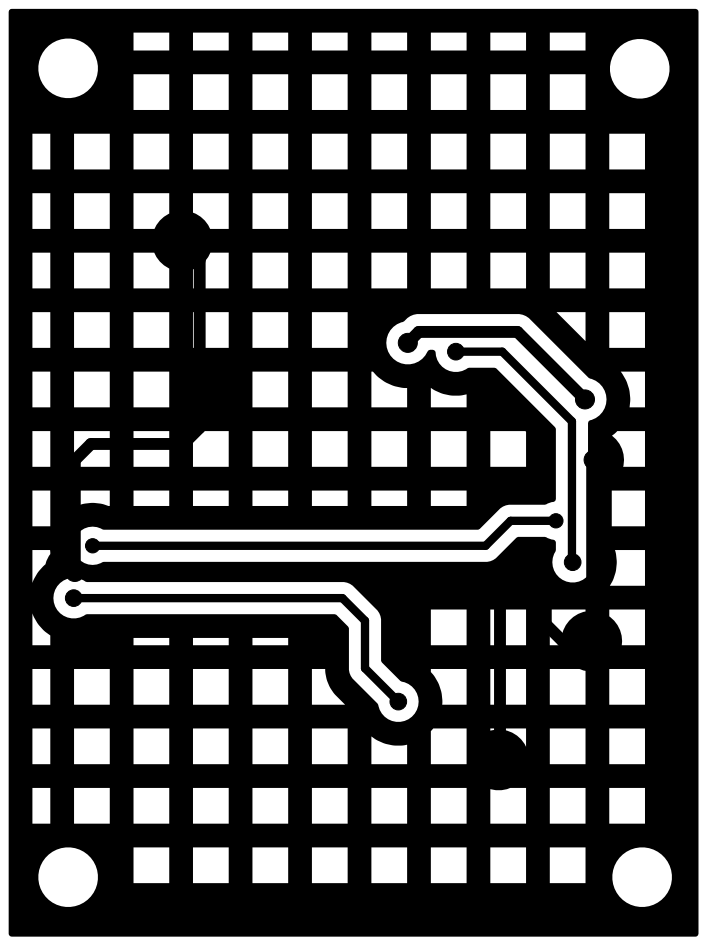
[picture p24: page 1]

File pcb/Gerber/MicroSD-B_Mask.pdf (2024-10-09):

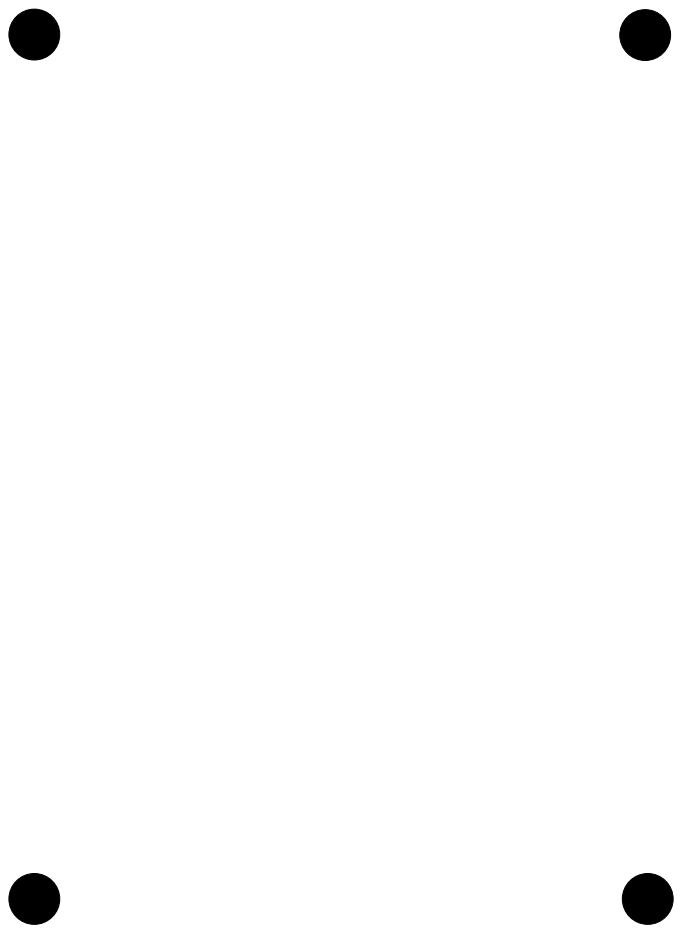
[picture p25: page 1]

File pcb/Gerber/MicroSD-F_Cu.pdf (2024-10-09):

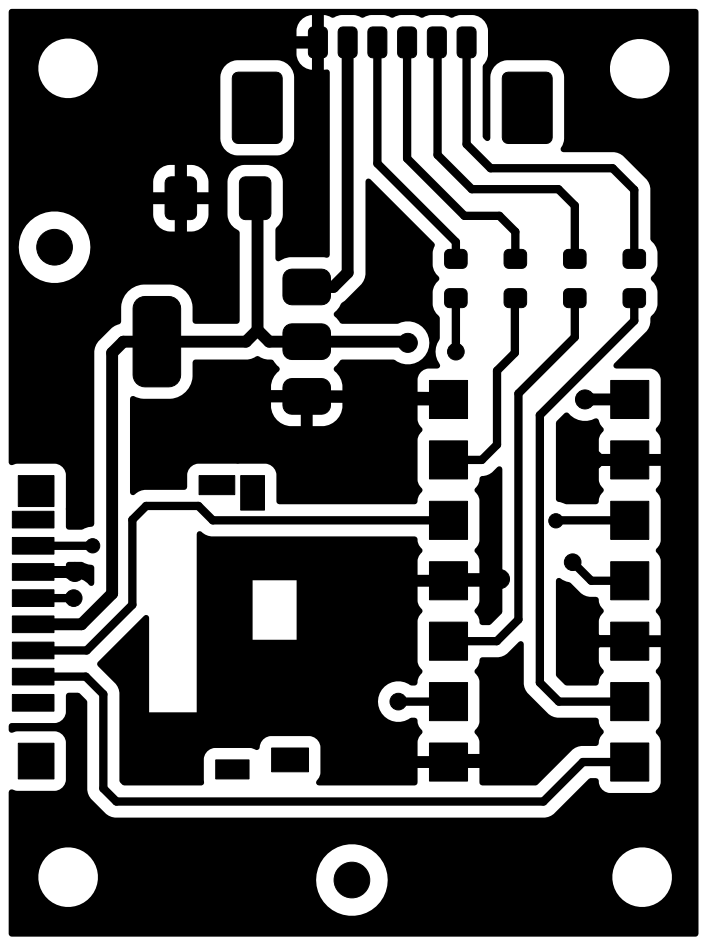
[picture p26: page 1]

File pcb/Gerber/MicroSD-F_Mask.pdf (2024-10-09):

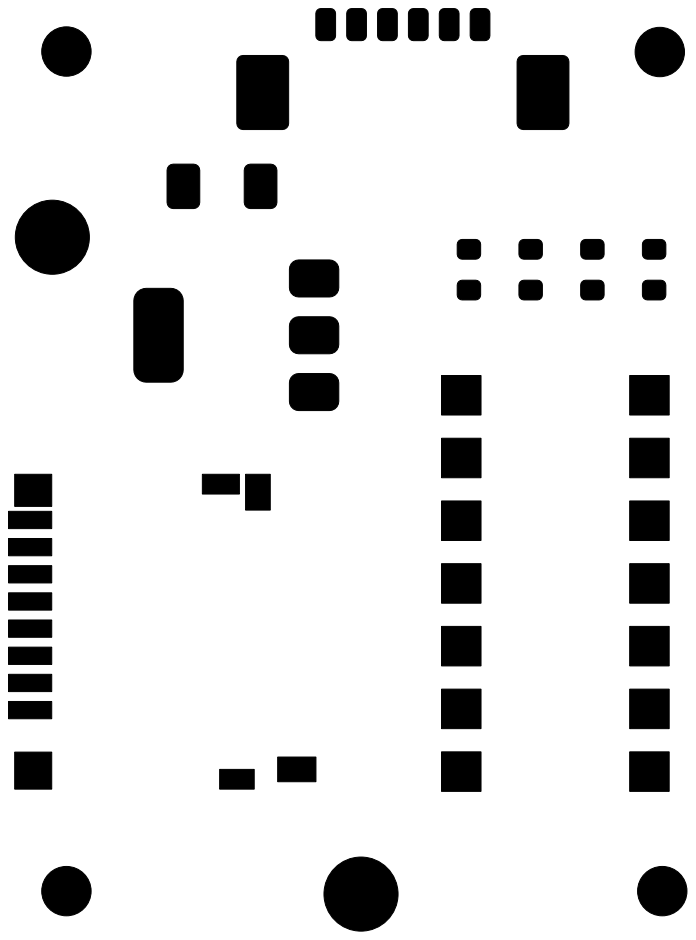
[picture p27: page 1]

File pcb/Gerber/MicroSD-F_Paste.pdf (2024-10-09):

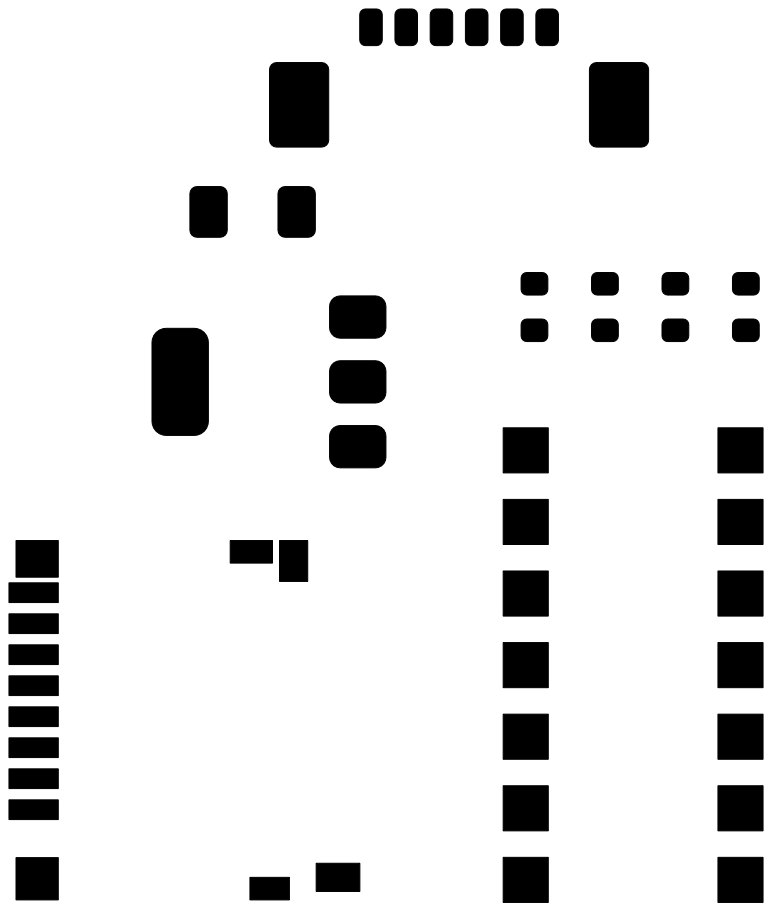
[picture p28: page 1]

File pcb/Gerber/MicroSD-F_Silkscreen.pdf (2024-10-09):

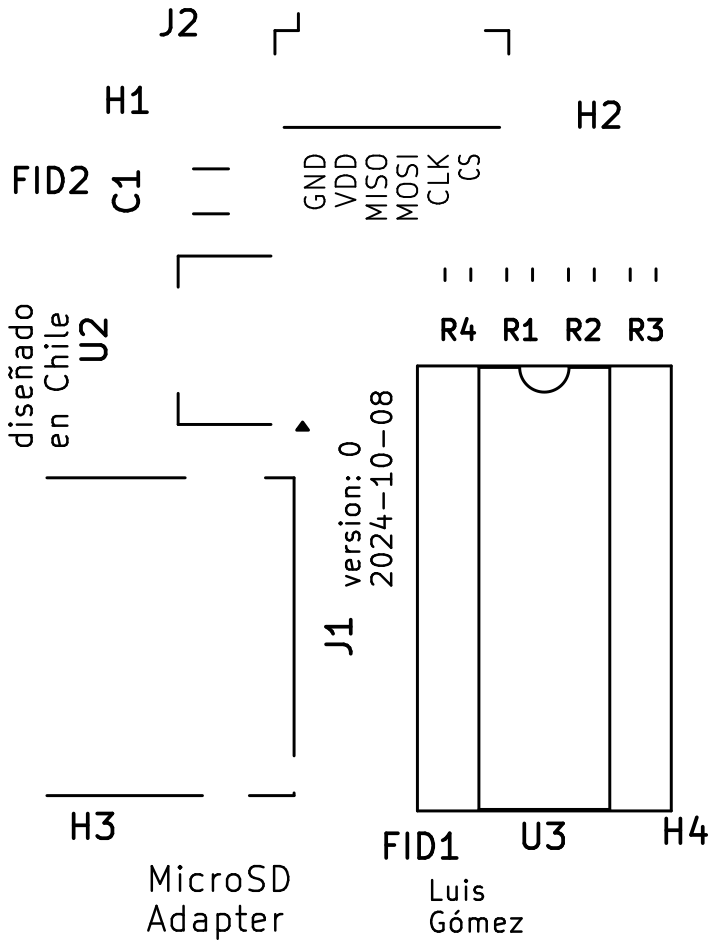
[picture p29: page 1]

Luis þÿGómez version: 0 2024-10-08 MicroSD

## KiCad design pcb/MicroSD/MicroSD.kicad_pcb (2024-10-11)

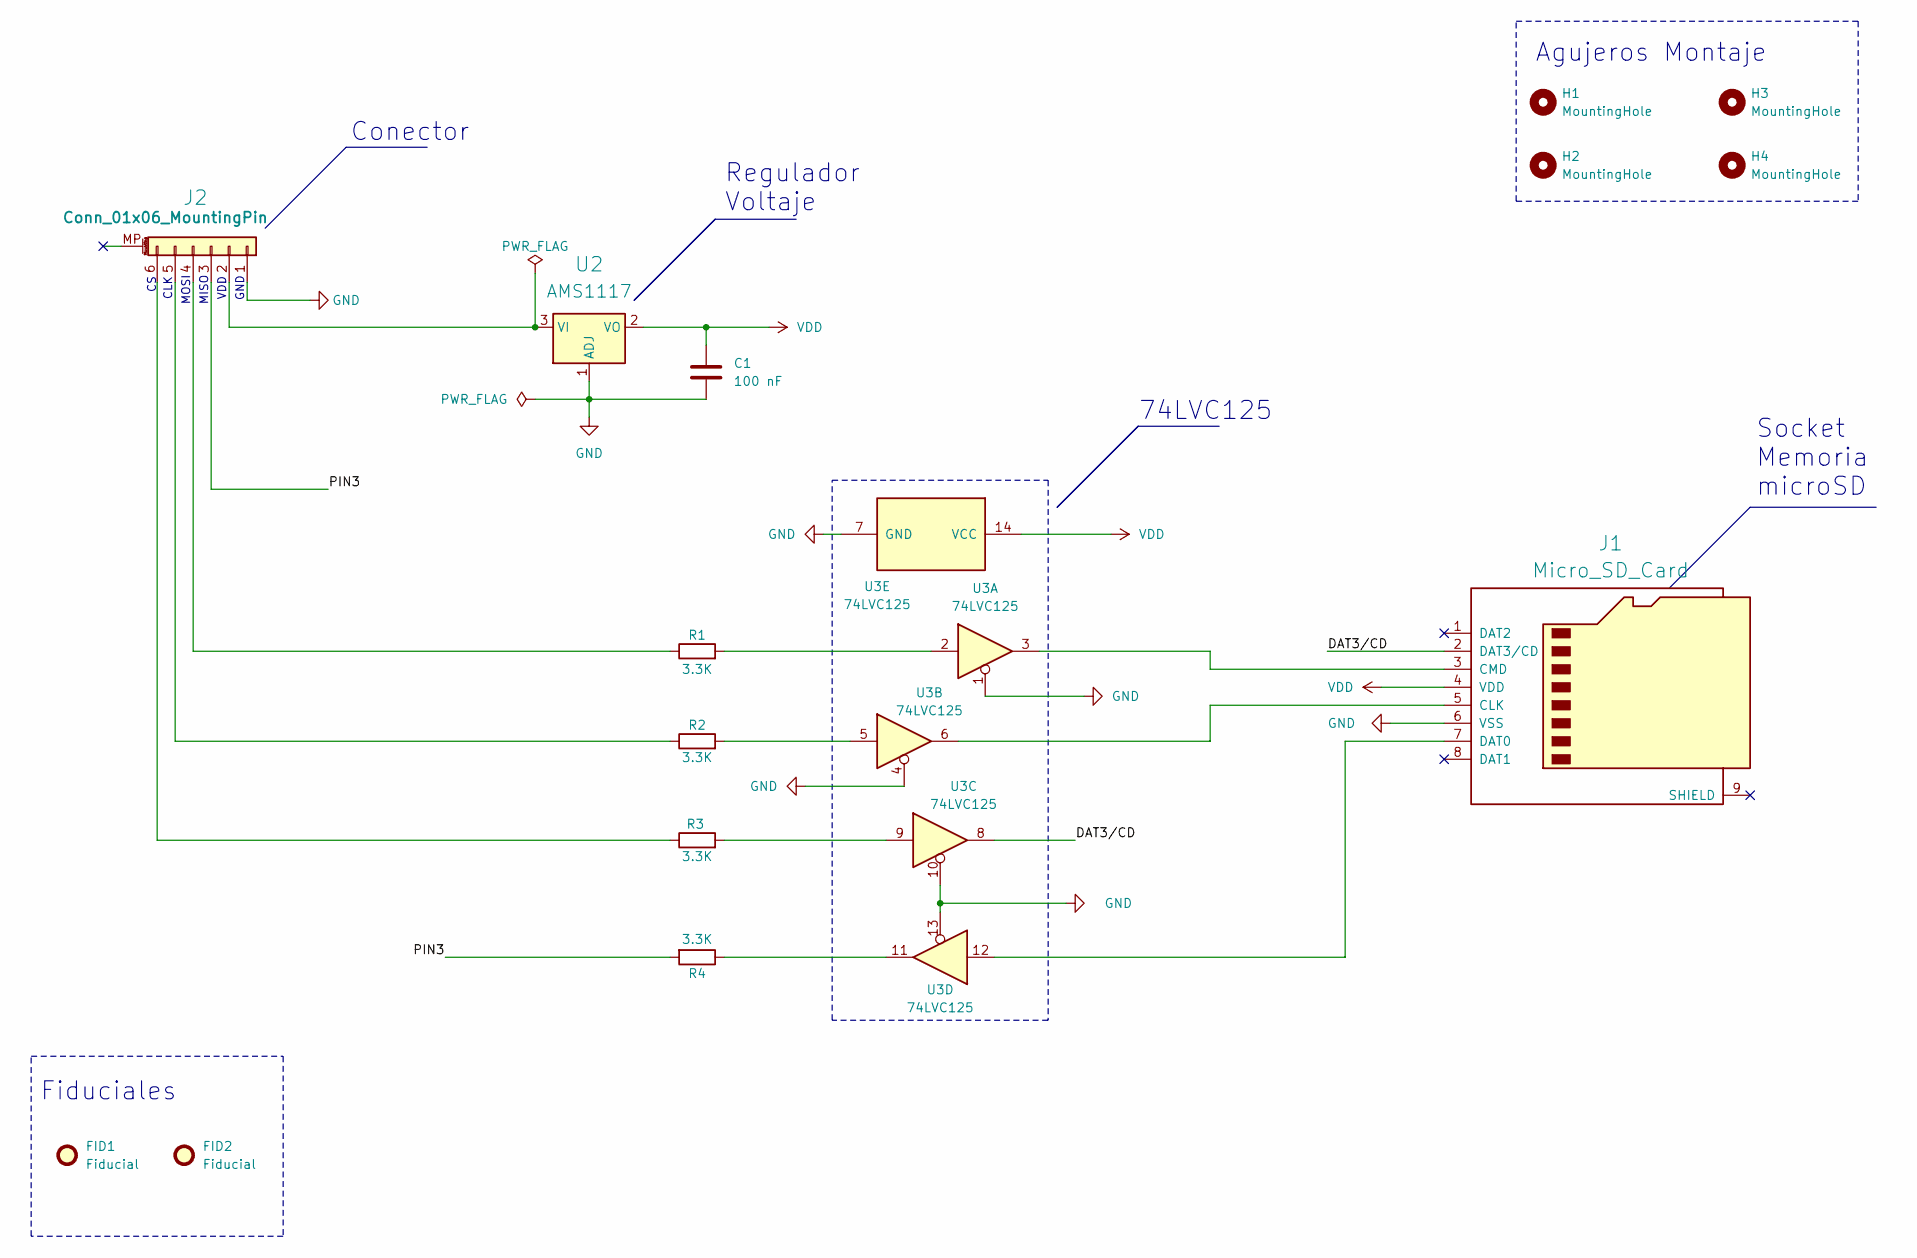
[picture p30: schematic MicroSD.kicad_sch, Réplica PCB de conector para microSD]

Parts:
C1: 100 nF; C_1206_3216Metric_Pad1.33x1.80mm_HandSolder
FID1, FID2: Fiducial; Fiducial_1.5mm_Mask3mm
H1, H2, H3, H4: MountingHole; MountingHole_2mm
J1: Micro_SD_Card; microSD_HC_Hirose_DM3D-SF
J2: Conn_01x06_MountingPin; Molex_PicoBlade_53398-0671_1x06-1MP_P1.25mm_Vertical
R1, R2, R3, R4: 3.3K; R_0603_1608Metric
U2: AMS1117; SOT-223-3_TabPin2
U3: 74LVC125; DIP-14_W7.62mm_SMDSocket_SmallPads

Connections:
/DAT3/CD: J1.2 (DAT3/CD), U3.8
/PIN3: J2.3, R4.2
GND: C1.2, J1.6 (VSS), J2.1, U2.1 (ADJ), U3.1, U3.4, U3.7 (GND), U3.10, U3.13
unnamed: J1.5 (CLK), U3.6
unnamed: J1.3 (CMD), U3.3
unnamed: J1.7 (DAT0), U3.12
unnamed: J2.2, U2.3 (VI)
unnamed: J2.4, R1.1
unnamed: J2.5, R2.1
unnamed: J2.6, R3.1
unnamed: R1.2, U3.2
unnamed: R2.2, U3.5
unnamed: R3.2, U3.9
unnamed: R4.1, U3.11
VDD: C1.1, J1.4 (VDD), U2.2 (VO), U3.14 (VCC)

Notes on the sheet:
VDD
CLK
MISO
Fiduciales
Conector
MOSI
GND
Socket Memoria microSD
74LVC125
Agujeros Montaje
Regulador Voltaje

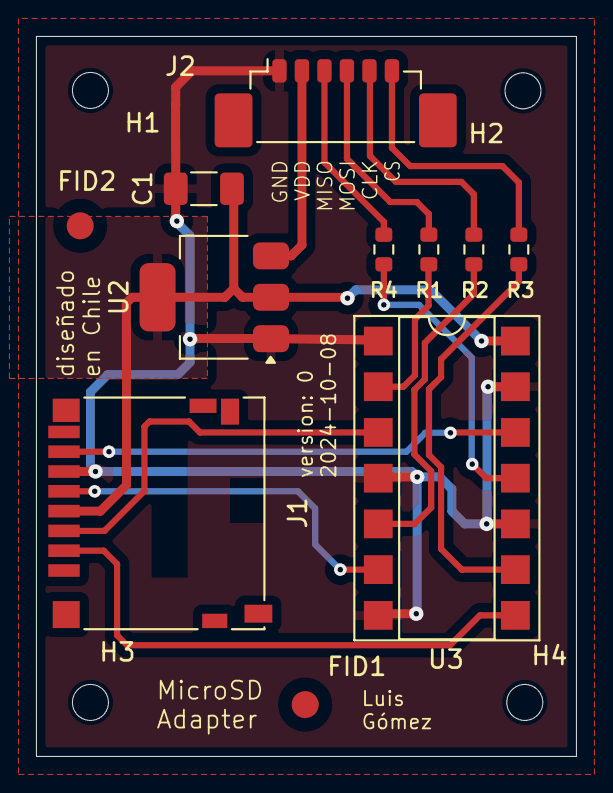
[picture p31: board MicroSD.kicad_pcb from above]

Board: 2 copper layers, 30.0 x 40.0 mm, 15 parts (0 on the bottom side), 15 nets.

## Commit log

2024-09-02 se gregan archivos proyecto
    [74LVC125APW_118.step, MicroSD.kicad_pcb, MicroSD.kicad_sch]
2024-09-15 actualizacion esquematico
    [MicroSD.kicad_pcb, MicroSD.kicad_sch]
2024-09-25 se agrega PCB
    [MicroSD.kicad_pcb, MicroSD.kicad_sch]
2024-09-25 se agrega PCB 2
2024-09-26 se agregan agujeros montaje
    [MicroSD.kicad_pcb, MicroSD.kicad_sch]
2024-10-08 se actualiza PCB y esquemas
    [MicroSD.kicad_pcb, MicroSD.kicad_sch]
2024-10-08 se actualiza PCB y esquemas 2
    [MicroSD.kicad_pcb, MicroSD.kicad_sch]
2024-10-09 se actualiza resultados
    [MicroSD-B_Cu.gbr, MicroSD-B_Mask.gbr, MicroSD-B_Paste.gbr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]
2024-10-09 se agregan figuras y gerber
2024-10-10 README doc 16
    [MicroSD-B_Cu.gbr, MicroSD-B_Mask.gbr, MicroSD-B_Paste.gbr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]
2024-10-10 README doc 18
    [MicroSD.kicad_pcb, MicroSD.kicad_sch]
2024-10-10 se cambia tamaño
    [MicroSD.kicad_pcb]
2024-10-11 se eliminan error del pcb
    [MicroSD.kicad_pcb]

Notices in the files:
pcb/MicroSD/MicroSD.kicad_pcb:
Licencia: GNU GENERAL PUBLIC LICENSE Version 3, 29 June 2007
